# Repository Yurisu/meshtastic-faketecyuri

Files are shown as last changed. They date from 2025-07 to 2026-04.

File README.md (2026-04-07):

# Meshtastic Low-Cost Controller Open Source Project

> 🌐 [中文版本 / Chinese Version](README_CN.md)

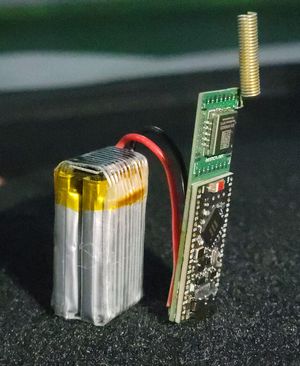
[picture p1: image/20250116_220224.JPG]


## Project Overview

A low-cost communication controller solution based on the Meshtastic protocol. It integrates solar charging, GPS positioning, and LoRa communication, making it ideal for IoT applications, off-grid communication, and especially solar-powered nodes.

One PCB is compatible with nearly all modules available on the market (great for budget builds).

This project is derived from https://github.com/gargomoma/fakeTec_pcb.

## Comparison with the Original fakeTec

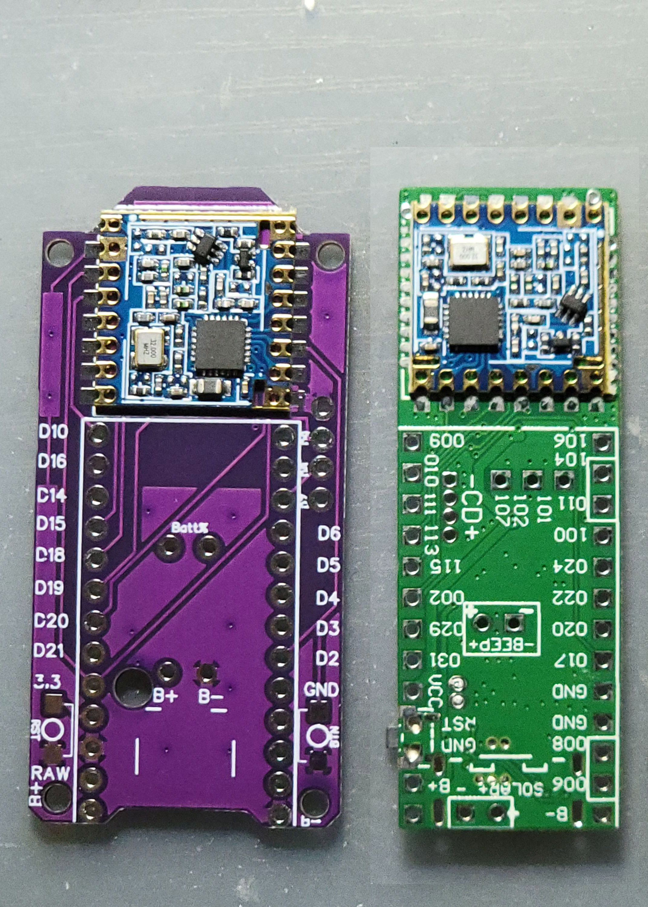
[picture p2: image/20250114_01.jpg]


## Feature Modules

### 1. Integrated Solar Charging

- [CN3163 Charge Management IC](https://item.szlcsc.com/582671.html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)

- Temperature protection range: 0–55°C (set via onboard NTC)

- NTC can be removed and replaced with the battery's internal NTC

- Current limiting resistor: 1.2KΩ (1000mA)

- Constant charge voltage: 4.2V

- Input voltage: 4.4–6V

- Dual status indicator outputs: charging and charge-complete

### 2. External Notification Components

**Buzzer**
- Driven via MOSFET (with freewheeling diode) — GPIO **38**
  Must be configured as `38` in both the **Device** page and the **External Notification** page.

**LED**
- External white LED — GPIO **33**
  Configure as `33` in the **External Notification** page only.

**User Button**
- Button KEY — GPIO **32** (default)
  No configuration needed.

**GPS Power Switch**
- GPS enable/disable driven via MOSFET
  Configure in the **Position** page: TX = `20`, RX = `22`, EN = `24`

### 3. GPS Hardware

| Component | Model | Notes |
| :--- | :--- | :--- |
| MCU | ProMicro NRF52840 | [ProMicro NRF52840 Dev Board (no soldering)](https://item.taobao.com/item.htm?id=752027856883&_u=e1fg9to98d5) |
| GPS | ATGM336H-5N71 | [BeiDou/GPS Module + Antenna](https://item.taobao.com/item.htm?id=649721823963&_u=e1fg9to3077) |
| Display | 0.96" SSD1306 OLED | [0.96" OLED IIC Interface](https://item.taobao.com/item.htm?id=537849751788&_u=e1fg9to677b) |

### 4. LoRa Modules

Supported LoRa modules:

| Manufacturer | Model | Notes |
| :--- | :--- | :--- |
| EByte (Chengdu) | E22-400M22S | [Buy Link](https://item.taobao.com/item.htm?id=571626367408&_u=e1fg9toef8a) |
| EByte (Chengdu) | E22-400MM22S | [Buy Link](https://item.taobao.com/item.htm?id=571626367408&_u=e1fg9toef8a) |
| Silicone Power (Shenzhen) | SX1268ZTR4 (433MHz) w/ spring antenna | [Buy Link](https://item.taobao.com/item.htm?id=631724138123&_u=e1fg9to418f) |
| Anxinke (Henan) | SX1268 Ra-01S w/ spring antenna | [Buy Link](https://item.taobao.com/item.htm?id=627657133308&_u=e1fg9toe418) |
| Huitt Automation | RA62 Module SX1262 (433–510MHz) | Untested, should work in theory. [Buy Link](https://item.taobao.com/item.htm?id=687692791680&_u=e1fg9toe418) |

> **Tip:** If you purchase the Anxinke SX1268 Ra-01S and the included antenna is tuned for 433MHz, trimming 3.5 coils will retune it to approximately 480MHz.

### 5. Changelog

**v1.1 Improvements**

- Added MOSFET pull-down resistors to eliminate leakage current

- Reordered GPS connector pinout for direct compatibility with the ATGM336H module

- Solar charging current increased to 1A — note: for batteries under 1Ah, reduce the charge current. A rate of 0.2×–0.5× battery capacity is recommended.

- Added MeshCN logo to PCB silkscreen

### 6. Quick Start

**Soldering Guide**

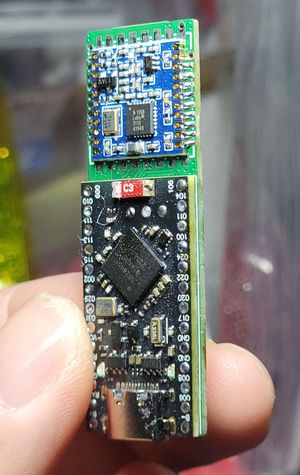
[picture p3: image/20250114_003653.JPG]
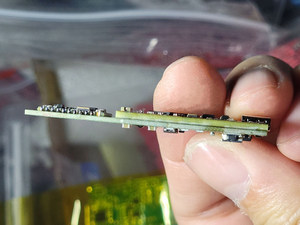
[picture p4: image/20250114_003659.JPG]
    
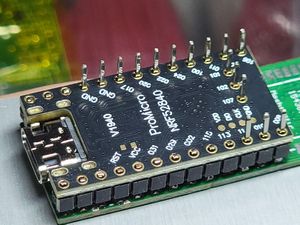
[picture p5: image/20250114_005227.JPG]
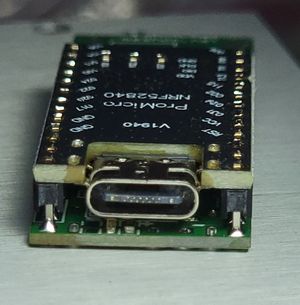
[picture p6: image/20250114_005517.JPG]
    

**PCB Photo**

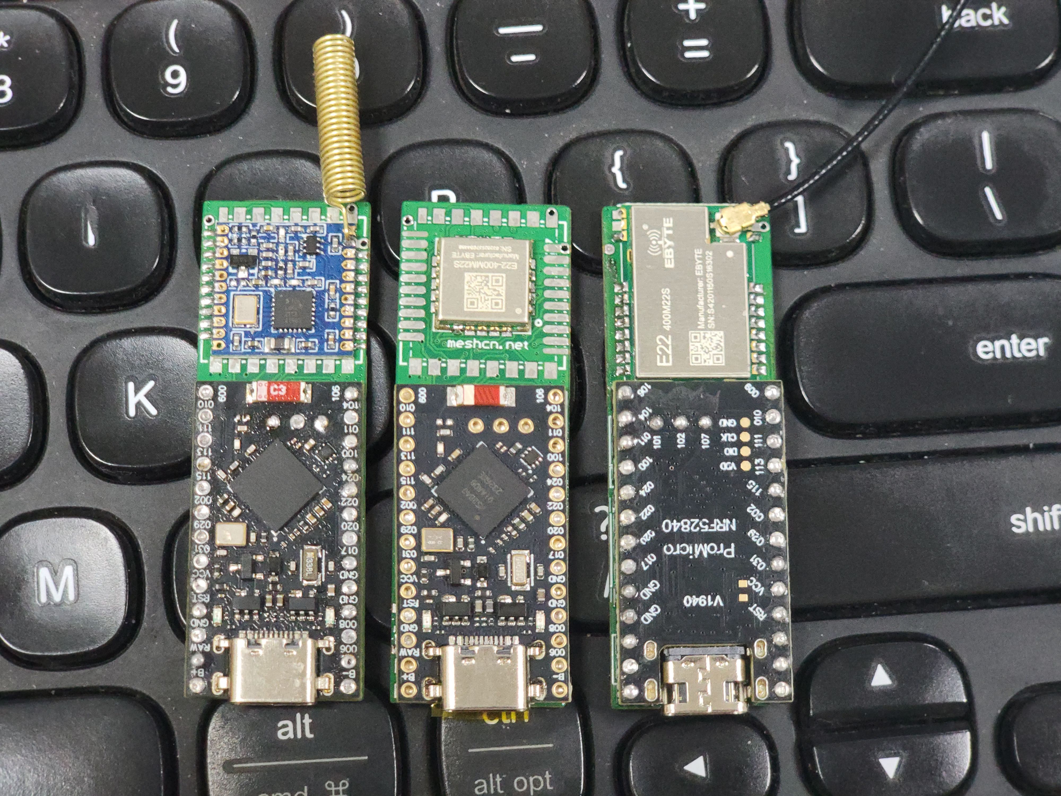
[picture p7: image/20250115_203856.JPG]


**PCB Render**

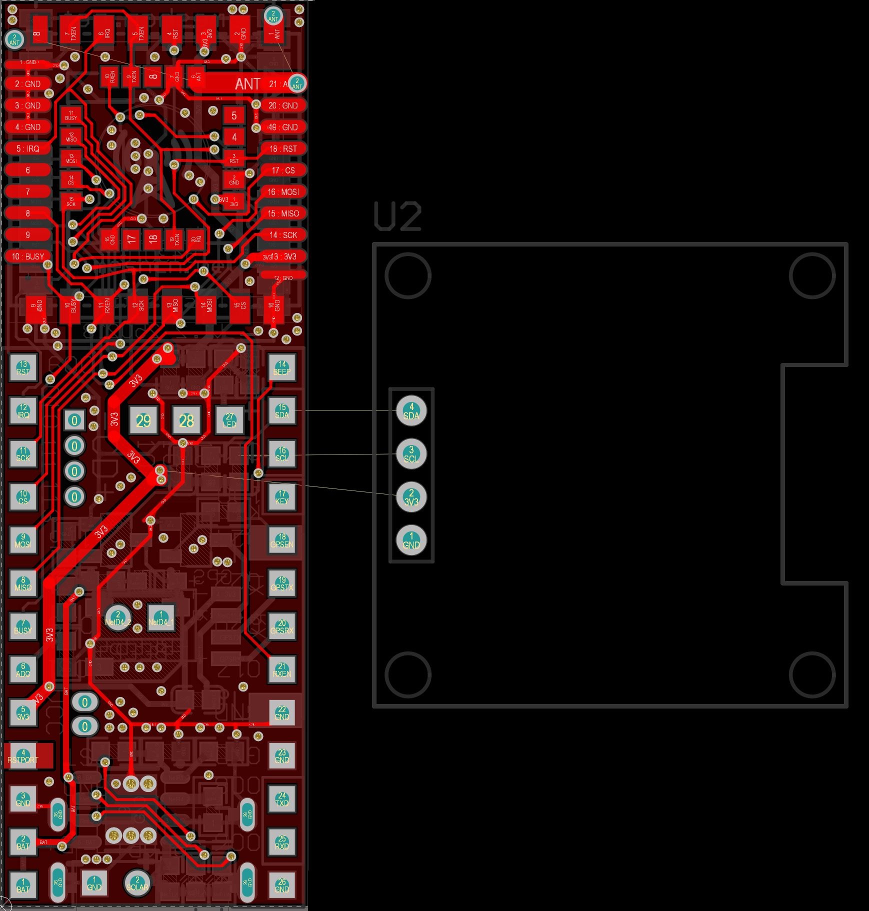
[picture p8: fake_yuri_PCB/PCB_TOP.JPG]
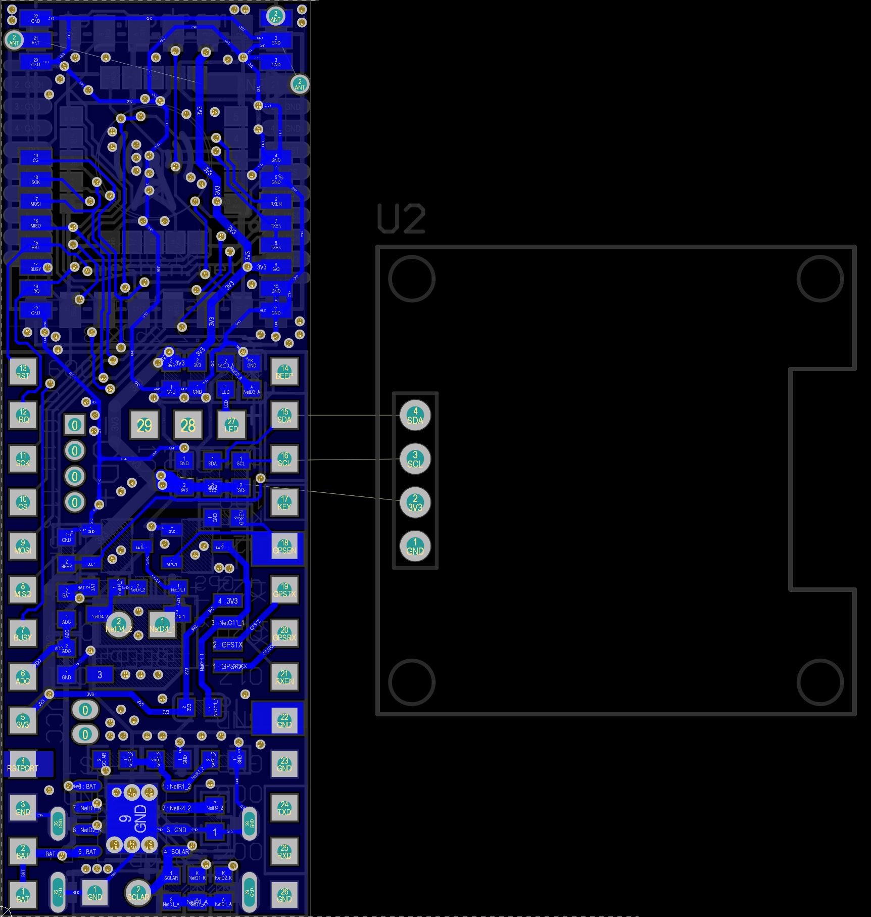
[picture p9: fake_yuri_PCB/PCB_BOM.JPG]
  

**Schematic**

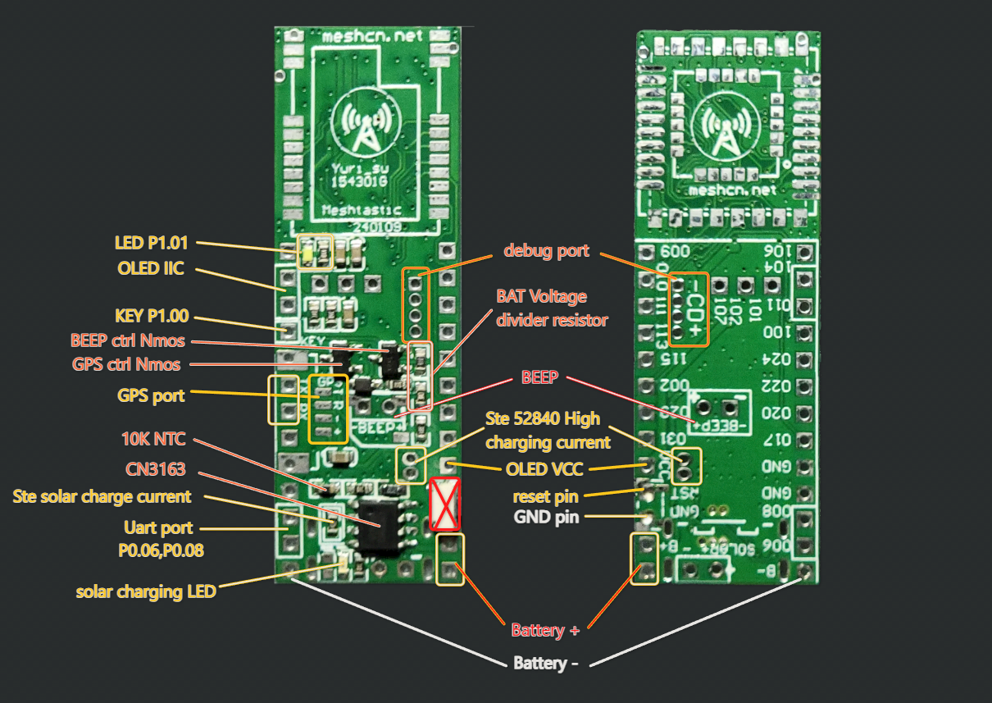
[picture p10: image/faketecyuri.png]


**Power Consumption Test Data**
https://meshcn.net/Meshtastic-LoRa-RF-Module-Power-Consumption-Test/

**SMD BOM**
https://github.com/Yurisu/meshtastic-faketecyuri/blob/main/fake_yuri_PCB/BOM_faketec52840.xls

**Real-World Communication Range Tests**

*(Coming soon)*

**Bootloader**
https://nicekeyboards.com/docs/nice-nano/getting-started/

Flash command:
```
adafruit-nrfutil dfu serial -p COM26 -pkg nice_nano_bootloader-0.9.2_s140_6.1.1.zip
```

**Meshtastic Firmware Compilation Guide**

*(Coming soon)*

**Verified Hardware Combinations**

*(Coming soon)*

**Known Compatibility Issues**

*(Coming soon)*

**Reserved IO Pin Definitions**

*(Coming soon)*

**Sensor Expansion Options**

*(Coming soon)*

**Community Support**
https://meshcn.net/

**Contributing**

*(Coming soon)*

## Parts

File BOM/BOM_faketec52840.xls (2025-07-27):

Designator | Description | Comment | Quantity | Footprint | #Column Name Error:' Note
C8, C9, C10, C11 | 贴片电容 | 22uF (226) 20% 6.3V | 4 | 0603_C
C12, C13 | 贴片电容 | 100nF (104) 10% 50V | 2 | 0603_C
C14, C15 | 贴片电容 | 22uF (226) 20% 25V | 2 | 0805_C
D1 | 发光二极管 | 红灯 0603 | 1 | 0603_LED_S1
D2 | 发光二极管 | 绿灯 0603 | 1 | 0603_LED_S1
D3 | 发光二极管 | 蓝灯 0603 | 1 | 0603_LED_S1
D4 | 二极管 | 1N4148WS T4 | 1 | SOD-323
LS1 | 蜂鸣器 | 5020蜂鸣器 | 1 | PB5020
Q1, Q3 | MOS(场效应管) | AO3400A N道沟 X0YV1T SOT-23 | 2 | SOT-23-3L
R1 | 贴片电阻 | SDNT1608X103F3450FTF | 1 | 0603_R
R2, R6, R7, R8, R9, R18 | 贴片电阻 | 10K | 6 | 0603_R
R3 | 贴片电阻 | 2K | 1 | 0603_R
R4 | 贴片电阻 | 1.2K | 1 | 0603_R
R12, R17 | 贴片电阻 | 10R | 2 | 0603_R
R13 | 贴片电阻 | 1M | 1 | 0603_R
R14 | 贴片电阻 | 1.5M | 1 | 0603_R
U3 | 太阳能充电IC | CN3163 | 1 | SOP-8_EP_150mil
U4 |  | SX1268TZR4-GC | 0 | SX1268TZR4-GC | 无线模块选一个
U5 |  | E22-400M22S | 0 | E22-400M22S
U7 |  | E22-400MM22S | 0 | E22-400MM22S
U8 |  | Ra-01s | 0 | RA-01
C16 |  | PROMICRO NRF52840 | 0 | PROMICRO NRF52840
U2 |  | OLED-HS96L03W2C03 | 0 | OLED-TH_L27.8-W27.2-P2.54_C9900033791
P2 |  | SOLAR | 0 | HDR1X2
P4 |  | GPS | 0 | HT1.25-4 | GPS插头
P5 |  | BEEP | 0 | HDR1X2

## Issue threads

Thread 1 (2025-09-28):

Are R18 and R13 the "bat voltage divide resistor" or are they R13 and R14?

Nombrealeatorio, 2025-09-28:
In the last updated image, R18 and R14 appear as "bat voltage divide resistors," but that doesn't make sense, since they are 10K and 1M.... Aren't R13 and R14-1.5M and 1M? That makes more sense.

Can I share the BOM and CPL files?

Also, I think this image might help with the assembly.
Thanks.

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

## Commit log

2025-07-21 add pcb proj
    [faketec-yuri_v1.1.PcbDoc, faketec-yuri_v1.1.SchDoc, faketec52840(yuri).PrjPcb]
2025-07-23 更新 README.md
2025-07-27 add bom
    [BOM_faketec52840.xls]
2025-07-27 fix bom
    [BOM_faketec52840.xls]
2025-07-28 add doc
    [BOM_faketec52840.xls, CN3163_Charging current calculation.xlsx]
2025-09-22 fix adc resistor position
